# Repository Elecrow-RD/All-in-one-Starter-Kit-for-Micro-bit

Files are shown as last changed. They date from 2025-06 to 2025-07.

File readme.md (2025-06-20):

### 1, Product picture

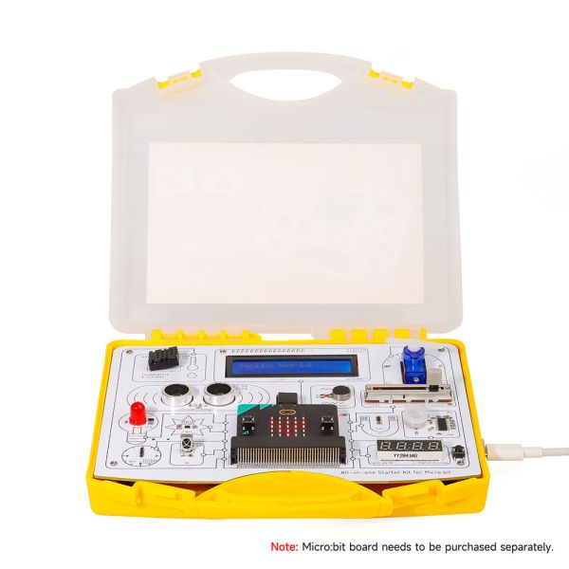
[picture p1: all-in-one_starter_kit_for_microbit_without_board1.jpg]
all-in-one_starter_kit_for_microbit_without_board1


https://www.elecrow.com/all-in-one-starter-kit-for-micro-bit-common-board-design-rich-modules-and-lessons.html

### 2, Product version number

| | Hardware | Software | Remark |
| ---- | --- | --- | --- |
| 1 | V1.0 | V1.0 | latest |

### 3, product information

- Main Processor IC: micro:bit
- Interface: Type-C Interface
- Size: 195\*170*46(mm)
- Material:PP(Non-toxic)
- Weight: 380g

| | [All-in-one Starter Kit for Micro:bit](https://www.elecrow.com/all-in-one-starter-kit-for-micro-bit-common-board-design-rich-modules-and-lessons.html) |
| --- | --- |
| Main Processor | micro:bit |
| Number of Sensors | 13 sensors |
| Sensor Board Design | Integrated sensor board, no soldering or complex wiring required |
| Programming Environment | Based on micro:bit visual modular programming |
| Number of Tutorials | 21 creative tutorials |
| Dimension | 195x170x46mm |
| Target Audience | Students, teachers, hardware enthusiasts |
| Application Scenarios | Ideal for learning micro:bit programming basics |

### 4,Quick Start

#### Go to the Micro:bit website:https://makecode.microbit.org/


#### Enter the online editor


### 5,Folder structure.

|--3D file： Contains 3D model files (.stp) for the hardware. These files can be used for visualization, enclosure design, or integration into CAD software.

|--Eagle_SCH&PCB: Contains **Eagle CAD** schematic (`.sch`) and PCB layout (`.brd`) files. These are used for circuit design and PCB manufacturing.

|--example: Provides example code and projects to demonstrate how to use the hardware and libraries. These examples help users get started quickly.

### 6,Pin definition

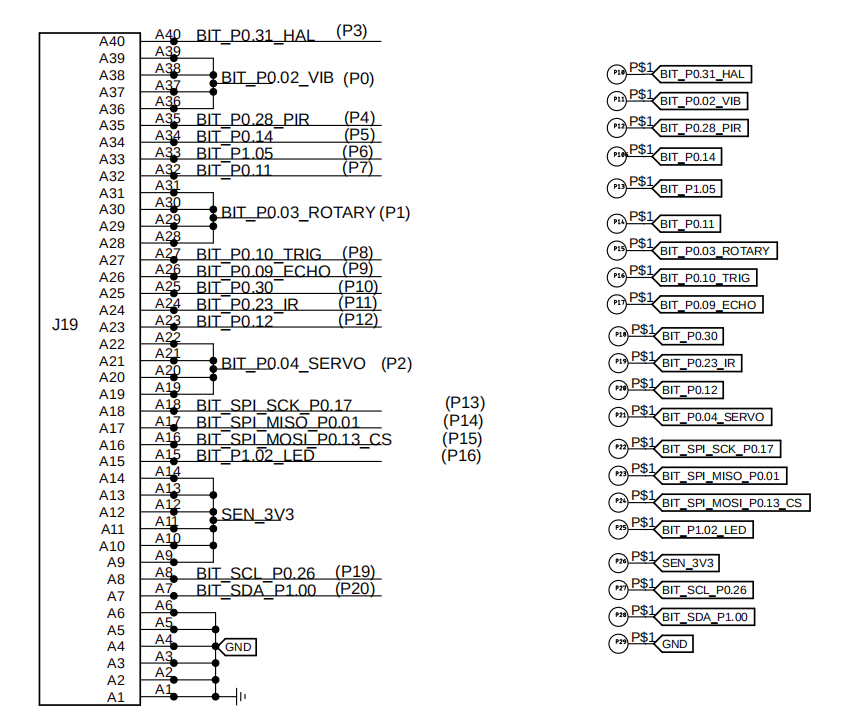
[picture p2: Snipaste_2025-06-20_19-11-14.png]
Snipaste_2025-06-20_19-11-14


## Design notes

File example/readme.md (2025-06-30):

**makecode**: This folder contains sample programs for the makecode platform, link:https://makecode.microbit.org/.

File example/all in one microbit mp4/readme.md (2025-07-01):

All-in-One Micro:bit Course Code Recording

In the course, the DHT20 and MyServo libraries won’t show up if you search by name, but you can find them by using their direct links instead.

DHT20：

https://github.com/MKleinSB/pxt-dht20

MyServo：

https://github.com/myrobotbit/PXT-MyServo

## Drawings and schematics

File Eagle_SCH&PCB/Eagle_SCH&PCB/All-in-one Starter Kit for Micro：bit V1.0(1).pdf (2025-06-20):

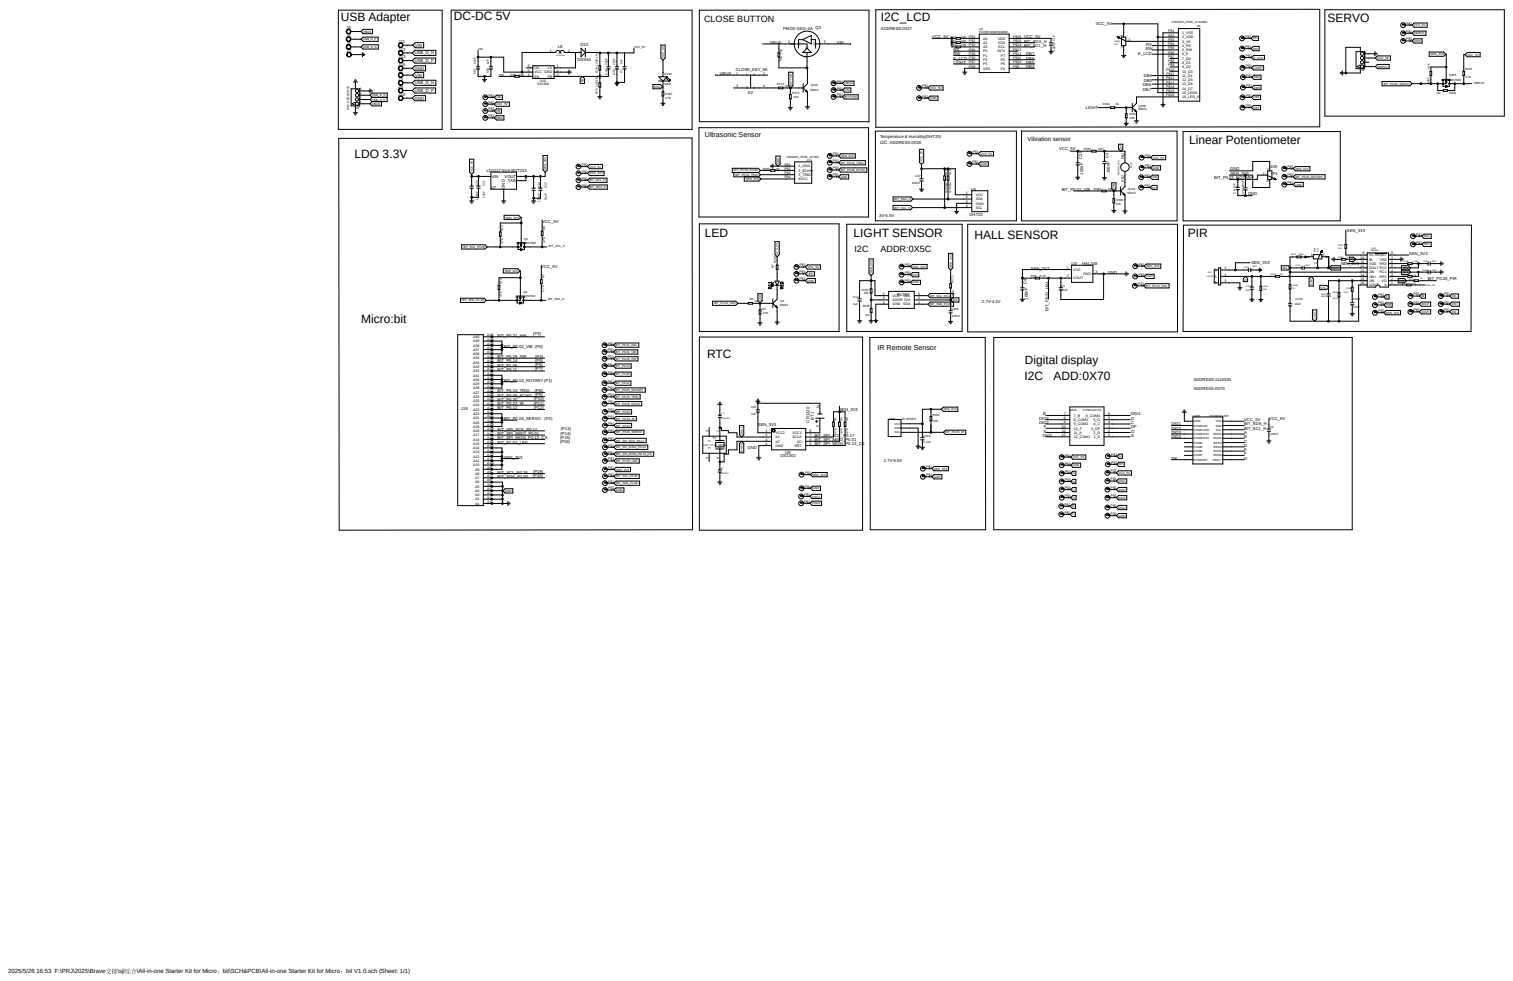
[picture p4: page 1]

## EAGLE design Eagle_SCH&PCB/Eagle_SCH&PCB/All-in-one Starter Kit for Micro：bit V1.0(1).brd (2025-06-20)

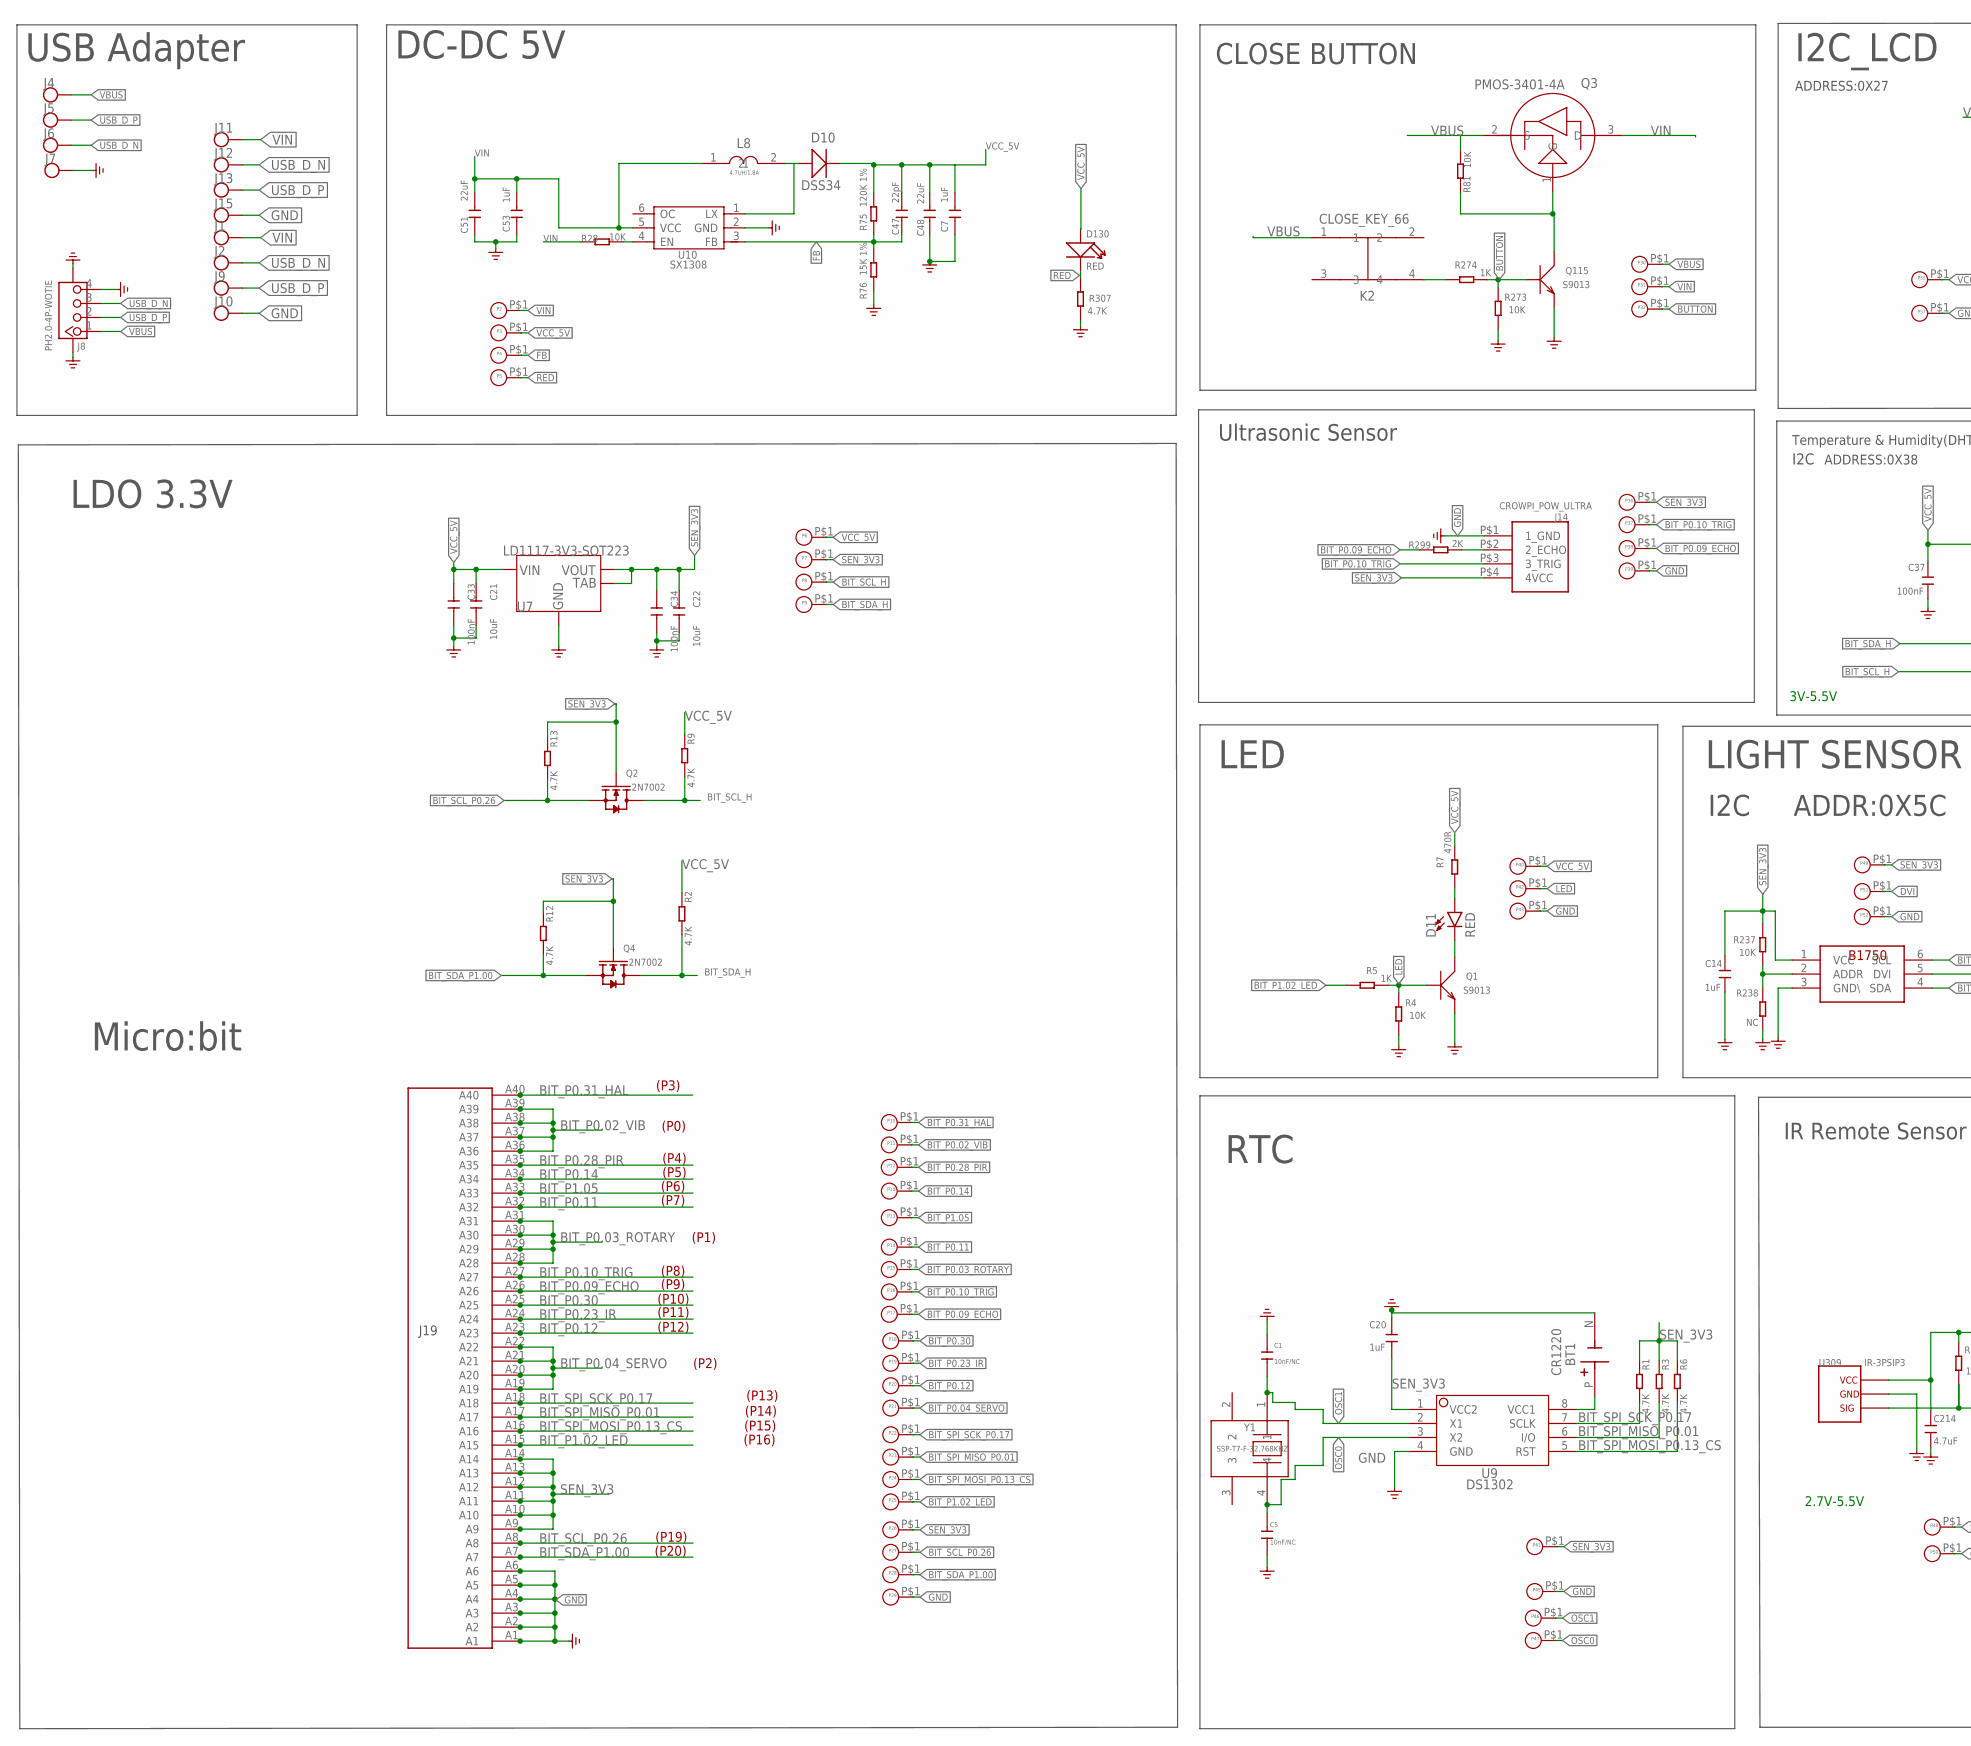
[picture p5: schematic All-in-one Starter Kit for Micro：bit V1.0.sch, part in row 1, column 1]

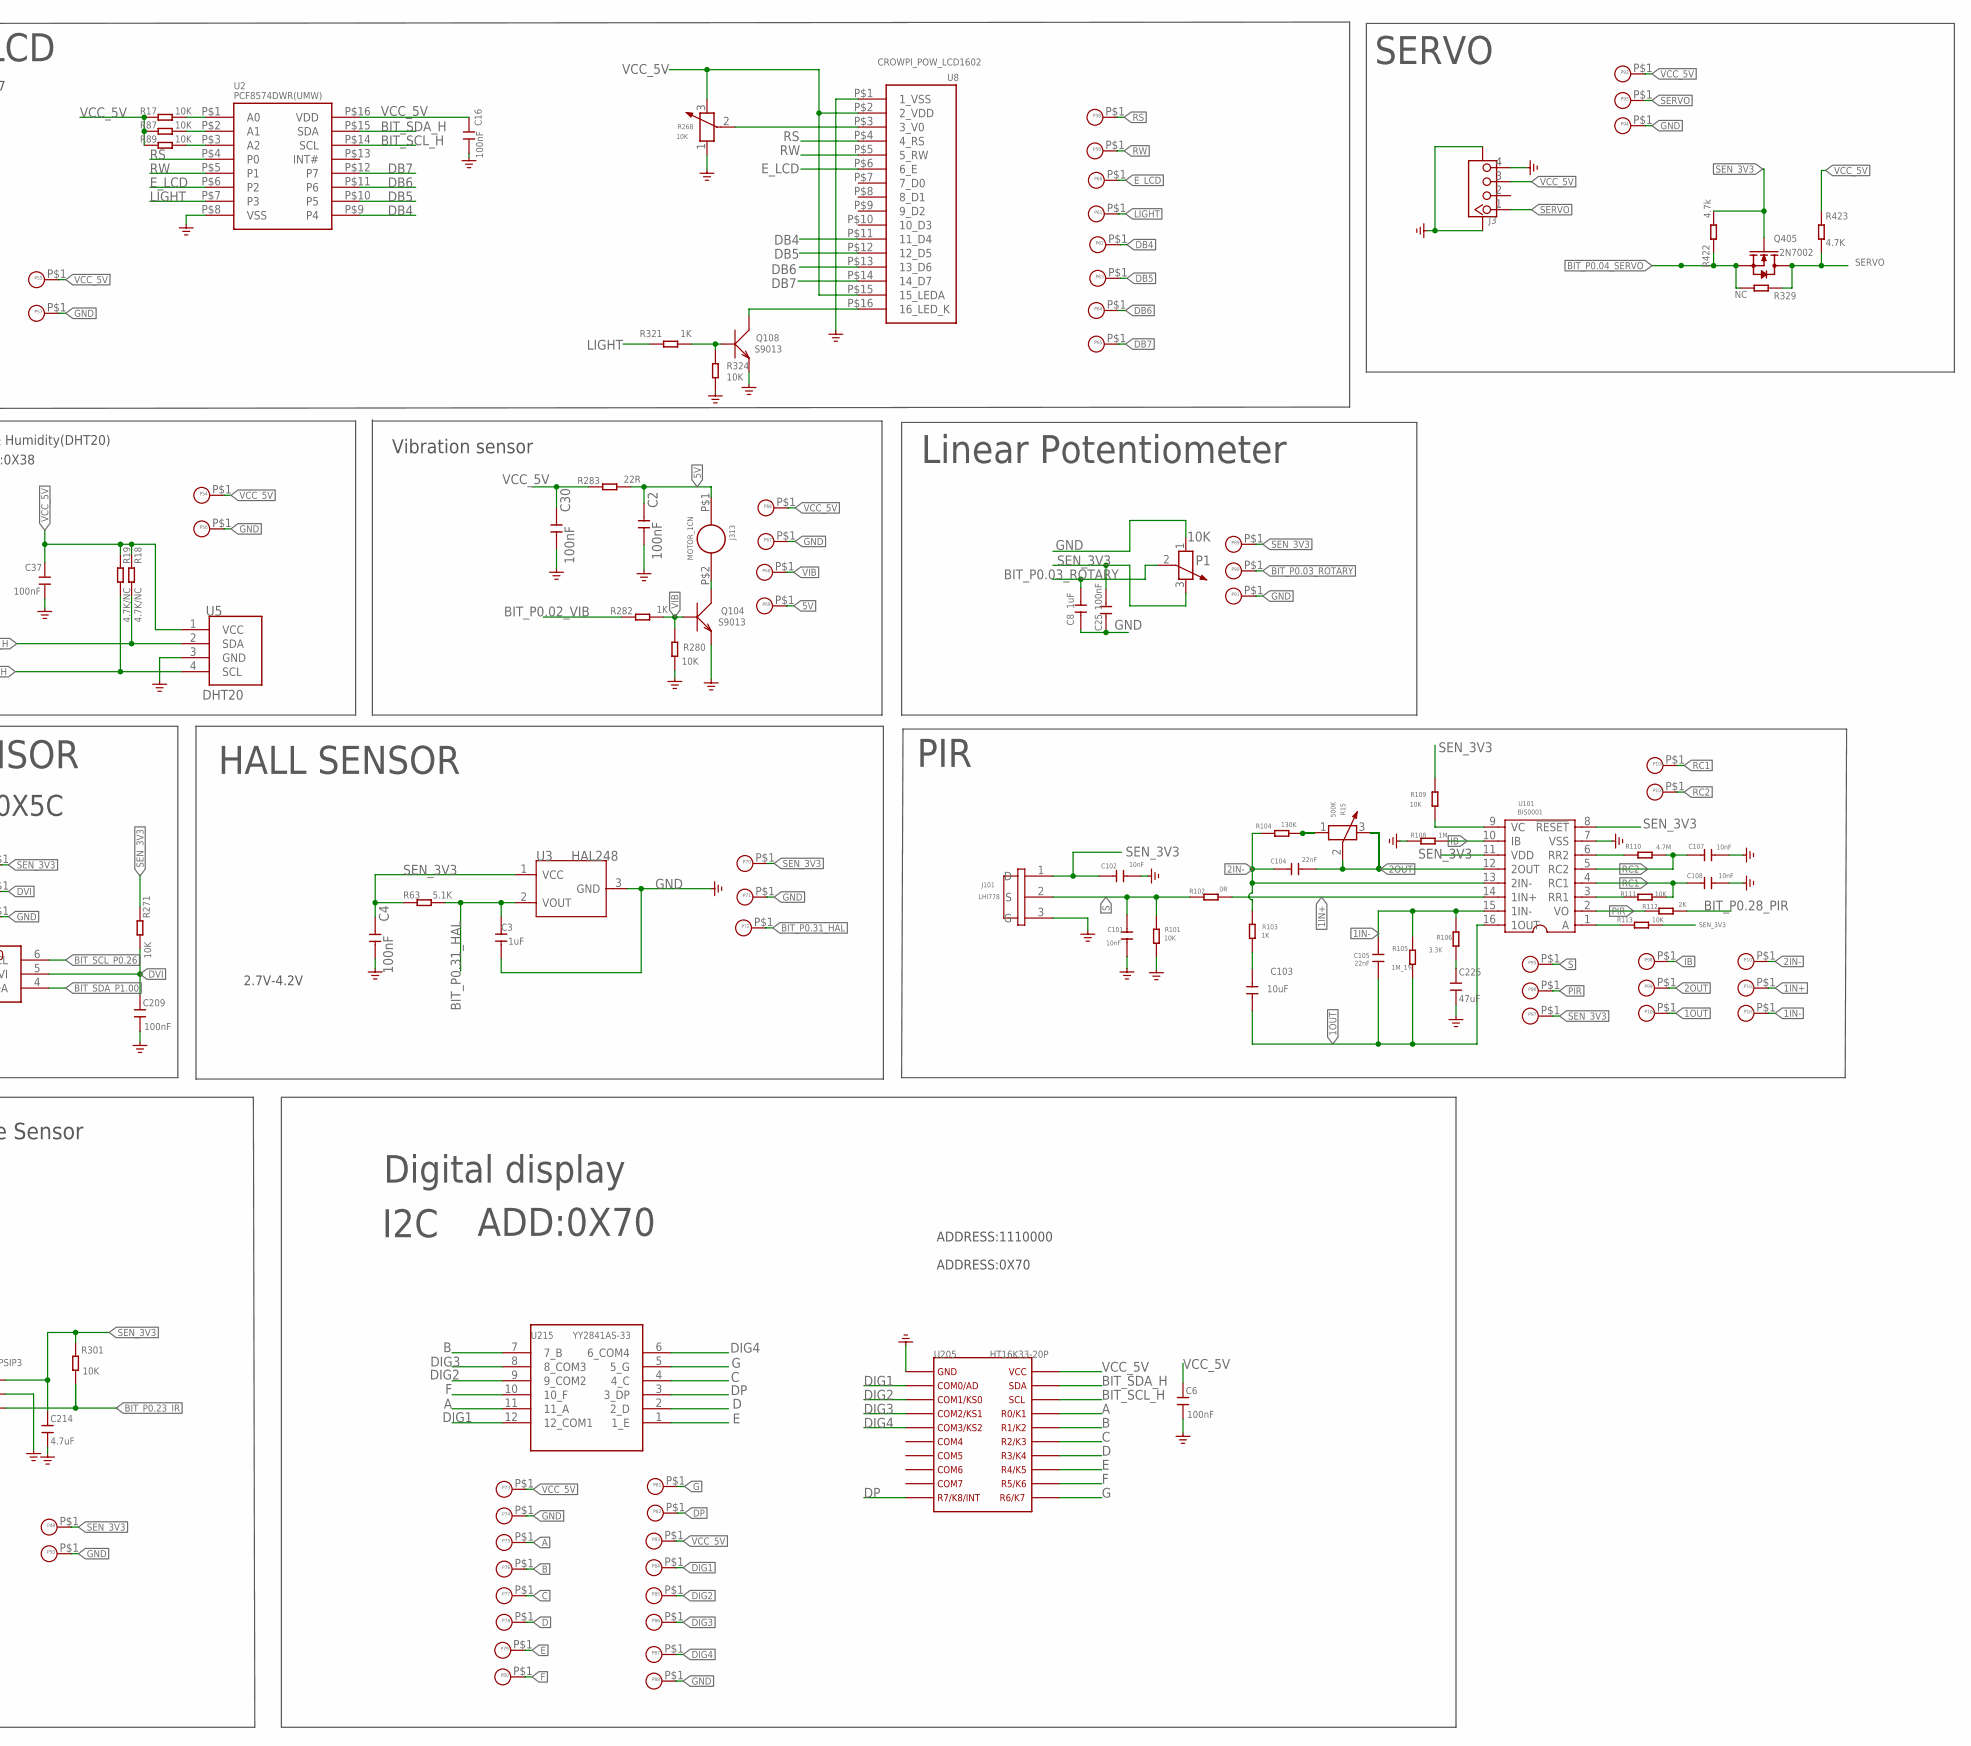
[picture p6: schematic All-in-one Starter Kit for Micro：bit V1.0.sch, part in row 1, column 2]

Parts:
BT1: CR1220
C1, C5: 10nF/NC; C0603
C2, C4, C25, C30, C33, C34: 100nF; C0603
C3, C7, C8, C20, C53: 1uF; C0603
C6, C16, C37, C209: 100nF; 0603
C14: 1uF; 0603
C21, C22: 10uF; C0603
C47: 22pF; C0603
C48, C51: 22uF; C0805
C101, C102, C107, C108: 10nF; C0603
C103: 10uF; 0603
C104, C105: 22nF; C0603
C214: 4.7uF; 0603
C225: 47uF; 0805
D10: DSS34; D_SOD123FL
D11: RED; LED-8MM
D130: RED; LED_0603_SMT
J1, J2, J4, J5, J6, J7, J9, J10, J11, J12, J13, J15: TP-SMDTP-SMD-2X4MM; TP-SMD-2X4MM
J3: A_XBJ_CONNECTOR_TWIG-4P-2.0-SMD-FEMALE-REINFORCE9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; A_XBJ_CONNECTOR_4P-SMD-2.0-90D
J8: PH2.0-4P-WOTIE; PH2.0-4P
J14: CROWPI_POW_ULTRA
J19: MICROBIT_SMD_40P
J101: LHI778; 3P-D8.1MM
J313: MOTOR_1CN; MOTOR_1CM
K2: CLOSE_KEY_66; CLOSE_KEY_6*6
L8: 4.7UH/1.8A; 1008
P1: 10K; 3P-SQUA-45.6X10X5.8H
P2, P3, P4, P5, P6, P7, P8, P9, P10, P11, P12, P13, P14, P15, P16, P17, P18, P19, P20, P21, P22, P23, P24, P25, P26, P27, P28, P29, P30, P31, P32, P36, P37, P38, P39, P40, P41, P42, P43, P45, P46, P47, P48, P49, P50, P51, P52, P54, P55, P56, P57, P58, P59, P60, P61, P62, P63, P64, P65, P66, P67, P68, P69, P70, P71, P72, P73, P74, P75, P76, P77, P78, P79, P80, P81, P82, P83, P84, P85, P86, P87, P88, P89, P90, P91, P92, P93, P94, P95, P96, P97, P98, P99, P100, P101, P102, P103, P104, P105, P106: PADPAD-1.0MM; PAD-1.0MM
Q1, Q104, Q108, Q115: S9013; SOT23@1
Q2, Q4, Q405: 2N7002; SOT23
Q3: PMOS-3401-4A; DFN8_SOT-23
R1, R2, R3, R6, R9, R12, R13, R307, R423: 4.7K; R0603
R4, R17, R87, R89, R101, R109, R111, R113, R237, R271, R273, R280, R301, R324: 10K; R0603
R5, R103, R274, R282, R321: 1K; R0603
R7: 470R; R0603
R15: 500K; 3P-SMD-SQUA-3.6X3.3
R18, R19: 4.7K/NC; R0603
R28: 10K; R0603-SP
R63: 5.1K; R0603
R75: 120K 1%; R0603-SP
R76: 15K 1%; R0603-SP
R81: 10K; DISCRETE_R0603
R102: 0R; R0603
R104: 130K; R0603
R105: 1M_1%; R0603
R106: 3.3K; R0603
R108: 1M; R0603
R110: 4.7M; R0603
R112, R299: 2K; R0603
R238, R329: NC; R0603
R268: 10K; 3P-SMD-SQUA-3.6X3.3
R283: 22R; R0603
R422: 4.7k; R0603
U1: BH1750; BH1750-WSOF-6
U2: PCF8574DWR(UMW); SO-16-300MIL
U3: HAL248; SOT-23W
U5: DHT20; CROWTAIL-DHT20-V1.0-20211013_DHT20
U7: LD1117-3V3-SOT223; SOT223
U8: CROWPI_POW_LCD1602; CROWPI_POW_LCD1206
U9: DS1302; SOP8
U10: SX1308; SOT23-6L
U101: BIS0001; SOP16
U205: HT16K33-20P; HT16K33-SOP20
U215: YY2841AS-33; 4-DIGITAL_DISPLAY
U309: IR-3PSIP3; VS1838B-SIP3
Y1: SSP-T7-F-32.768KHZ; MC-146

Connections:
1IN+: P102.P$1, R102.1, U101.14 (1IN+)
1IN-: C105.2, P103.P$1, R105.2, R106.2, U101.15 (1IN-)
1OUT: C103.2, C105.1, P100.P$1, R105.1, U101.16 (1OUT)
2IN-: C104.1, P101.P$1, R103.2, R104.2, U101.13 (2IN-)
2OUT: C104.2, P99.P$1, R15.2 (3), R15.3 (2), U101.12 (2OUT)
5V: C2.2, J313.P$1, P69.P$1, R283.2
A: P75.P$1, U205.P$17, U215.11 (11_A)
B: P76.P$1, U205.P$16, U215.7 (7_B)
BIT_P0.02_VIB: J19.A36, J19.A37, J19.A38, J19.A39, P11.P$1, R282.1
BIT_P0.03_ROTARY: C8.2, J19.A28, J19.A29, J19.A30, J19.A31, P1.2 (3), P15.P$1, P90.P$1
BIT_P0.04_SERVO: J19.A19, J19.A20, J19.A21, J19.A22, P21.P$1, Q405.2 (S), R329.2, R422.1
BIT_P0.09_ECHO: J19.A26, P17.P$1, P38.P$1, R299.2
BIT_P0.10_TRIG: J14.P$3 (3_TRIG), J19.A27, P16.P$1, P37.P$1
BIT_P0.11: J19.A32, P14.P$1
BIT_P0.12: J19.A23, P20.P$1
BIT_P0.14: J19.A34, P106.P$1
BIT_P0.23_IR: J19.A24, P19.P$1, R301.2, U309.3
BIT_P0.28_PIR: J19.A35, P12.P$1, R112.1
BIT_P0.30: J19.A25, P18.P$1
BIT_P0.31_HAL: C3.1, J19.A40, P10.P$1, P72.P$1, R63.1, U3.2 (VOUT)
BIT_P1.02_LED: J19.A15, P25.P$1, R5.2
BIT_P1.05: J19.A33, P13.P$1
BIT_SCL_H: P8.P$1, Q2.3 (D), R9.2, R19.2, U2.P$14 (SCL), U5.4 (SCL), U205.P$18
BIT_SCL_P0.26: J19.A8, P27.P$1, Q2.2 (S), R13.2, U1.6 (SCL)
BIT_SDA_H: P9.P$1, Q4.3 (D), R2.2, R18.2, U2.P$15 (SDA), U5.2 (SDA), U205.P$19
BIT_SDA_P1.00: J19.A7, P28.P$1, Q4.2 (S), R12.2, U1.4 (SDA)
BIT_SPI_MISO_P0.01: J19.A17, P23.P$1, R3.2, U9.6 (I/O)
BIT_SPI_MOSI_P0.13_CS: J19.A16, P24.P$1, R6.2, U9.5 (RST)
BIT_SPI_SCK_P0.17: J19.A18, P22.P$1, R1.2, U9.7 (SCLK)
BUTTON: P32.P$1, Q115.1 (B), R273.2, R274.1
C: P77.P$1, U205.P$15, U215.4 (4_C)
D: P78.P$1, U205.P$14, U215.2 (2_D)
DB4: P62.P$1, U2.P$9 (P4), U8.P$11 (11_D4)
DB5: P63.P$1, U2.P$10 (P5), U8.P$12 (12_D5)
DB6: P64.P$1, U2.P$11 (P6), U8.P$13 (13_D6)
DB7: P65.P$1, U2.P$12 (P7), U8.P$14 (14_D7)
DIG1: P84.P$1, U205.P$2, U215.12 (12_COM1)
DIG2: P85.P$1, U205.P$3, U215.9 (9_COM2)
DIG3: P86.P$1, U205.P$4, U215.8 (8_COM3)
DIG4: P87.P$1, U205.P$5, U215.6 (6_COM4)
DP: P82.P$1, U205.P$10, U215.3 (3_DP)
DVI: C209.2, P51.P$1, R271.2, U1.5 (DVI)
E: P79.P$1, U205.P$13, U215.1 (1_E)
E_LCD: P60.P$1, U2.P$6 (P2), U8.P$6 (6_E)
F: P80.P$1, U205.P$12, U215.10 (10_F)
FB: C47.2, P4.P$1, R75.1, R76.2, U10.3 (FB)
G: P81.P$1, U205.P$11, U215.5 (5_G)
GND: BT1.N (-), C1.2, C2.1, C3.2, C4.1, C5.1, C6.1, C7.1, C8.1, C14.1, C16.1, C20.2, C21.2, C22.2, C25.1, C30.1, C33.2, C34.2, C37.1, C48.1, C51.1, C53.1, C101.1, C102.1, C107.2, C108.2, C209.1, C214.1, C225.1, J3.4, J3.SS1, J3.SS2, J7.1, J8.4, J8.5 (SS1), J8.6 (SS2), J10.1, J14.P$1 (1_GND), J15.1, J19.A1, J19.A2, J19.A3, J19.A4, J19.A5, J19.A6, J101.3 (G), P1.1, P29.P$1, P39.P$1, P43.P$1, P45.P$1, P50.P$1, P52.P$1, P56.P$1, P57.P$1, P67.P$1, P71.P$1, P74.P$1, P88.P$1, P91.P$1, P94.P$1, Q1.2 (E), Q104.2 (E), Q108.2 (E), Q115.2 (E), R4.1, R76.1, R101.1, R108.1, R238.1, R268.1, R273.1, R280.1, R307.2, R324.2, U1.3 (GND\), U2.P$8 (VSS), U3.3 (GND), U5.3 (GND), U7.1 (GND), U8.P$1 (1_VSS), U9.4 (GND), U10.2 (GND), U101.7 (VSS), U205.P$1, U309.2
IB: P98.P$1, R108.2, U101.10 (IB)
LED: P42.P$1, Q1.1 (B), R4.2, R5.1
LIGHT: P61.P$1, R321.2, U2.P$7 (P3)
unnamed: R111.1, U101.3 (RR1)
unnamed: Q108.1 (B), R321.1, R324.1
unnamed: C225.2, R106.1
unnamed: D10.+, L8.2, U10.1 (LX)
unnamed: Q3.1 (G), Q115.3 (C), R81.1
unnamed: R28.2, U10.4 (EN)
unnamed: R268.2 (3), U8.P$3 (3_V0)
unnamed: K2.4, R274.2
unnamed: BT1.P (+), U9.8 (VCC1)
unnamed: R17.2, U2.P$1 (A0)
unnamed: R87.2, U2.P$2 (A1)
unnamed: R89.2, U2.P$3 (A2)
unnamed: D11.2 (C), Q1.3 (C)
unnamed: D11.1 (A), R7.2
unnamed: Q108.3 (C), U8.P$16 (16_LED_K)
unnamed: R110.2, U101.6 (RR2)
unnamed: R109.2, U101.9 (VC)
unnamed: C103.1, R103.1
unnamed: R113.2, U101.1 (A)
unnamed: R15.1, R104.1
unnamed: J313.P$2, Q104.3 (C)
unnamed: R237.1, R238.2, U1.2 (ADDR)
unnamed: J14.P$2 (2_ECHO), R299.1
OSC0: C5.2, P47.P$1, U9.3 (X2), Y1.4
OSC1: C1.1, P46.P$1, U9.2 (X1), Y1.1
PIR: P96.P$1, R112.2, U101.2 (VO)
RC1: C108.1, P104.P$1, R111.2, U101.4 (RC1)
RC2: C107.1, P105.P$1, R110.1, U101.5 (RC2)
RED: D130.2 (2_K), P5.P$1, R307.1
RS: P58.P$1, U2.P$4 (P0), U8.P$4 (4_RS)
RW: P59.P$1, U2.P$5 (P1), U8.P$5 (5_RW)
S: C101.2, J101.2 (S), P95.P$1, R101.2, R102.2
SEN_3V3: C4.2, C14.2, C20.1, C22.1, C25.2, C34.1, C102.2, C214.2, J14.P$4 (4VCC), J19.A9, J19.A10, J19.A11, J19.A12, J19.A13, J19.A14, J101.1 (D), P1.3 (2), P7.P$1, P26.P$1, P36.P$1, P41.P$1, P48.P$1, P49.P$1, P70.P$1, P89.P$1, P97.P$1, Q2.1 (G), Q4.1 (G), Q405.1 (G), R1.1, R3.1, R6.1, R12.1, R13.1, R63.2, R109.1, R113.1, R237.2, R271.1, R301.1, R422.2, U1.1 (VCC), U3.1 (VCC), U7.2 (VOUT), U7.4 (TAB), U9.1 (VCC2), U101.8 (!RESET), U101.11 (VDD), U309.1
SERVO: J3.1, P93.P$1, Q405.3 (D), R329.1, R423.2
USB_D_N: J2.1, J6.1, J8.3, J12.1
USB_D_P: J5.1, J8.2, J9.1, J13.1
VBUS: J4.1, J8.1, K2.1, P30.P$1, Q3.2 (S), R81.2
VCC_5V: C6.2, C7.2, C16.2, C21.1, C30.2, C33.1, C37.2, C47.1, C48.2, D10.-, D130.1 (1_A), J3.3, P3.P$1, P6.P$1, P40.P$1, P54.P$1, P55.P$1, P66.P$1, P73.P$1, P83.P$1, P92.P$1, R2.1, R7.1, R9.1, R17.1, R18.1, R19.1, R75.2, R87.1, R89.1, R268.3 (2), R283.1, R423.1, U2.P$16 (VDD), U5.1 (VCC), U7.3 (VIN), U8.P$2 (2_VDD), U8.P$15 (15_LEDA), U205.P$20
VIB: P68.P$1, Q104.1 (B), R280.2, R282.2
VIN: C51.2, C53.2, J1.1, J11.1, L8.1, P2.P$1, P31.P$1, Q3.3 (D), R28.1, U10.5 (VCC)

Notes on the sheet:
I2C_LCD
LIGHT SENSOR
SERVO
Ultrasonic Sensor
IR Remote Sensor
I2C
Temperature & Humidity(DHT20)
PIR
CLOSE BUTTON
2.7V-5.5V
3V-5.5V
ADDRESS:0X38
ADDRESS:0X27
LED
Linear Potentiometer
DC-DC 5V
USB Adapter
ADDR:0X5C
Micro:bit
(P20)
(P19)
(P16)
(P15)
(P14)
(P13)
(P2)
(P8)
(P9)
(P10)
(P11)
(P12)
(P1)
(P4)
(P5)
(P6)
(P7)
(P0)
(P3)
LDO 3.3V
Vibration sensor

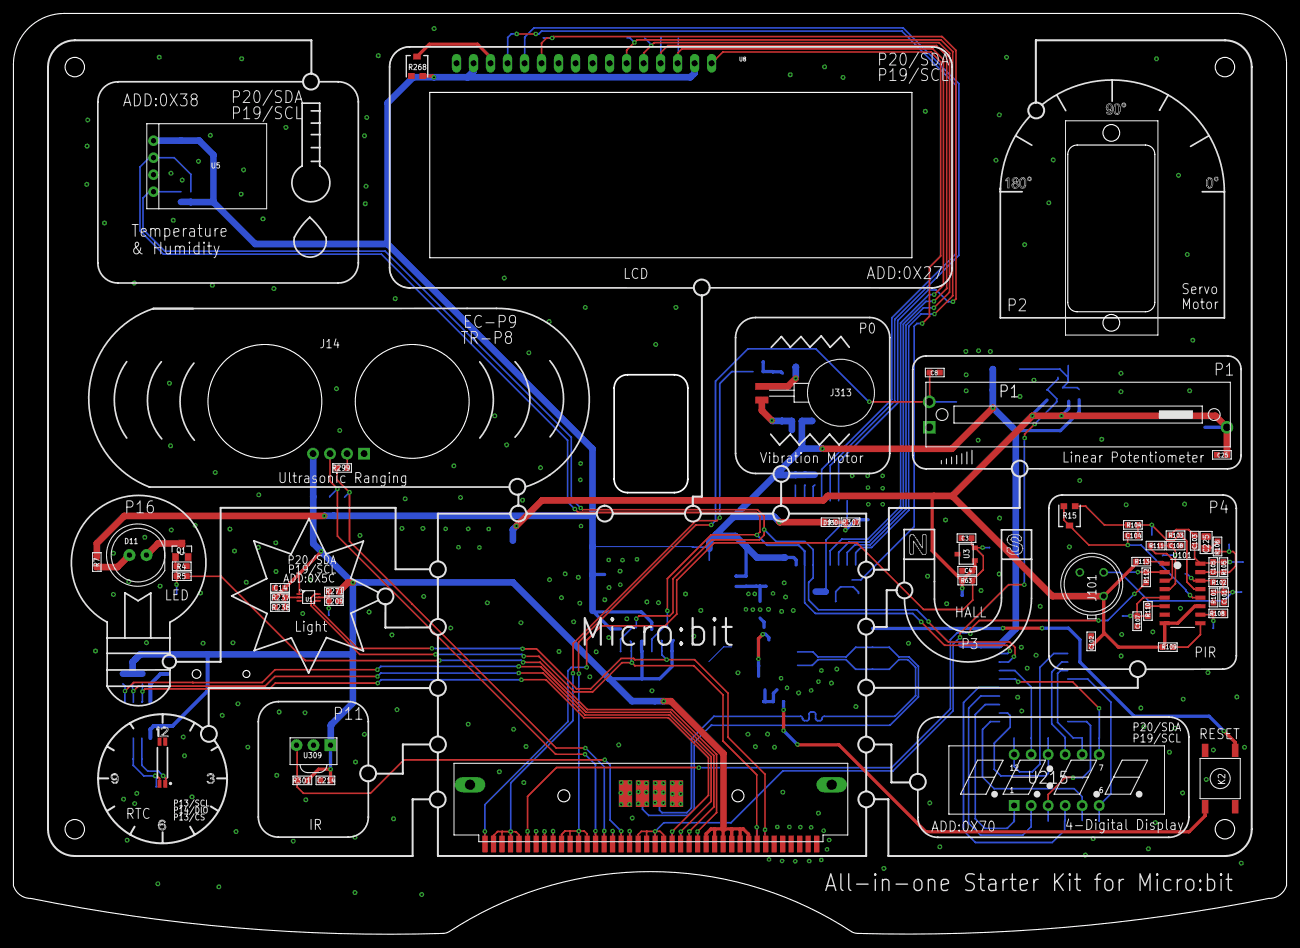
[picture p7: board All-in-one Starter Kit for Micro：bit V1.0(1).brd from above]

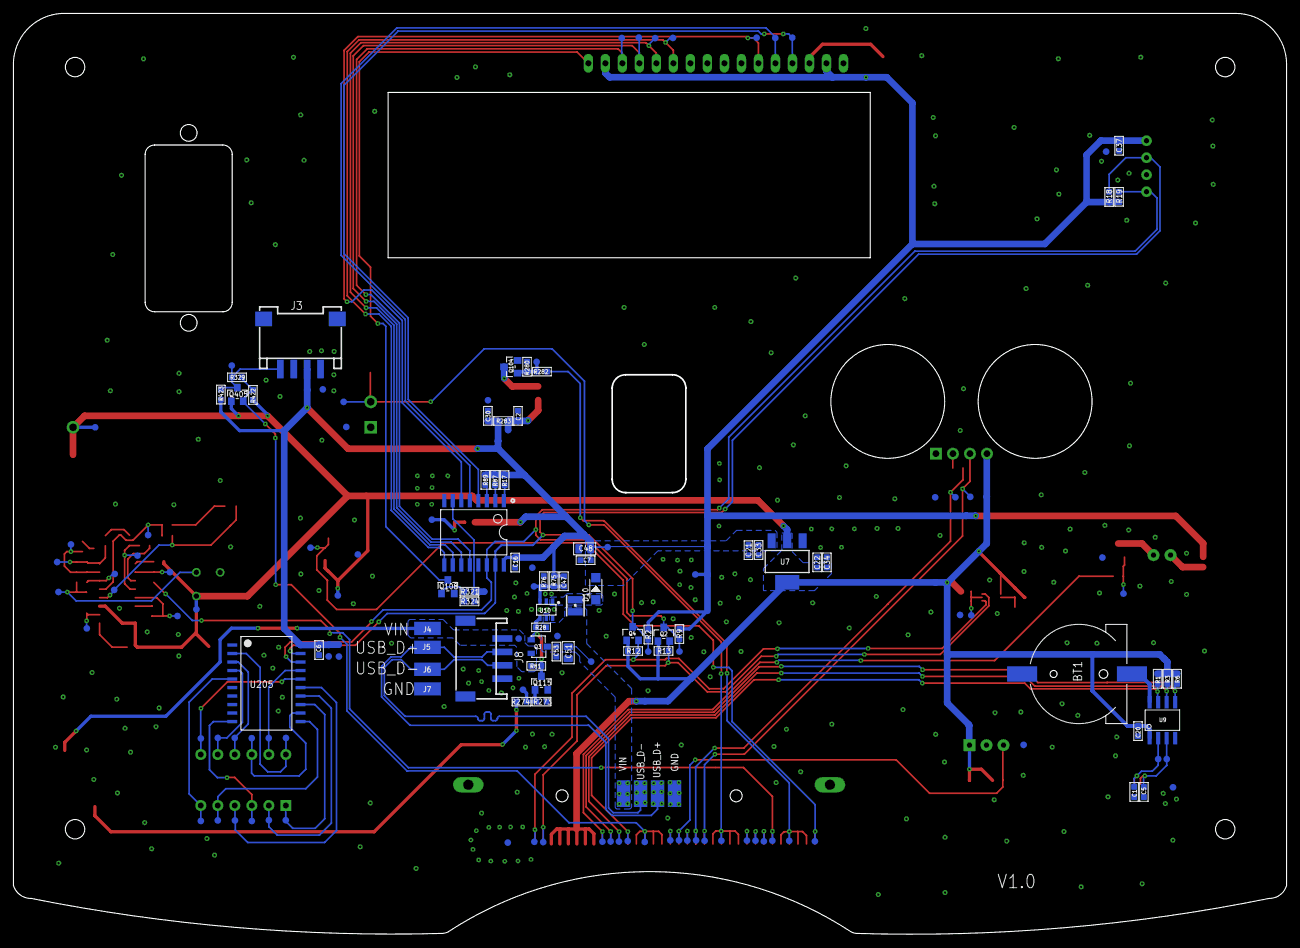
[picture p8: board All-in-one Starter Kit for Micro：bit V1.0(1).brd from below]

Board: 2 copper layers, 190.1 x 137.5 mm, 228 parts (168 on the bottom side), 91 nets.
